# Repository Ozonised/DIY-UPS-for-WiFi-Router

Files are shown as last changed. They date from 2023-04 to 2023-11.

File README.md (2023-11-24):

# DIY-UPS-for-WiFi-Router
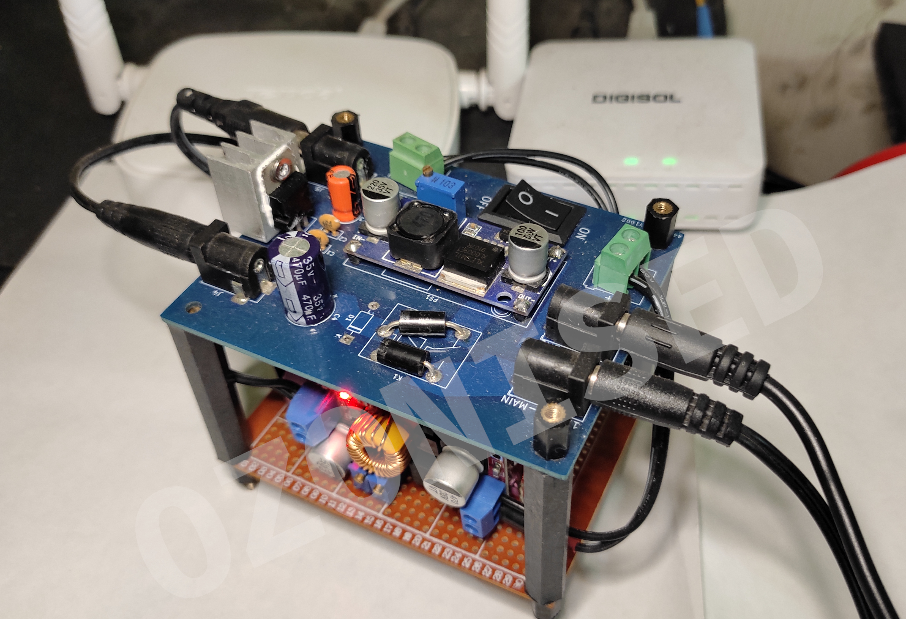
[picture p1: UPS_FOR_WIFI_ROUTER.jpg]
DIY_UPS_FOR_WIFI_ROUTER

A UPS for Wi-Fi routers and ONU with 4 hours of back-up.

# SPECIFICATIONS
Here is a breif table containing the main specs of the UPS:
| CATEGORY | VALUE |
| :---: | :---: |
| Back-UP time | Upto 4 hours|
| No. of Output ports | 2 |
| Output Voltage | 12V(1A) & 9V(800mA) |
| Input Voltage | 12V |
| Battery Type | 2s-2p li-ion |
| Battery Voltage | 7.4V(nominal) |
| Battery Capacity | 4000mAH |

# POWER
Unlike many commercial devices, this DIY UPS utilises 2 * 12 volt adapter. One for powering the Router and ONU, and the other for charging the batteries.
The adapter connected to the female barrel port labelled ```12V-IN-MAIN``` powers both the router and ONU, while the one connected to the female barrel port labelled ```12-IN-2ND``` is used for the charging the battery.
However, using two adapters is not a must, the entire thing can be powered by a single 12 volt adapter. To do so follow these steps:
- Short the pads ```TP1``` & ```TP2``` on the bottomside of the PCB.
- Now, plug the 12V adapter to the female barrel port labelled ```12V-IN-2ND```.

### Note:
 When using a single 12V adpater to power as well as charge the batteries, do not plug the 12V adapter into the female barrel port labelled ```12V-IN-MAIN```. Use the port labelled ```12V-IN-2ND```. Also use an adapter rated at-least 1.5 amps(2A is preferrable).

# BATTERY PACK
The battery is a 2s 2p lithium-ion pack with a nominal voltage of 7.4 volts and a capacity of, 4000mAh approximately.
The batteries are managed by this HW-882 3 A BMS for 2s lithium-ion battery pack.
Soldering the components on the PCB is a straight forward as everything is labelled. This is why I decided to skip the soldering part and focus on the wiring of the battery pack and XL4015 to the PCB.

## WIRING OF THE BATTERY PACK
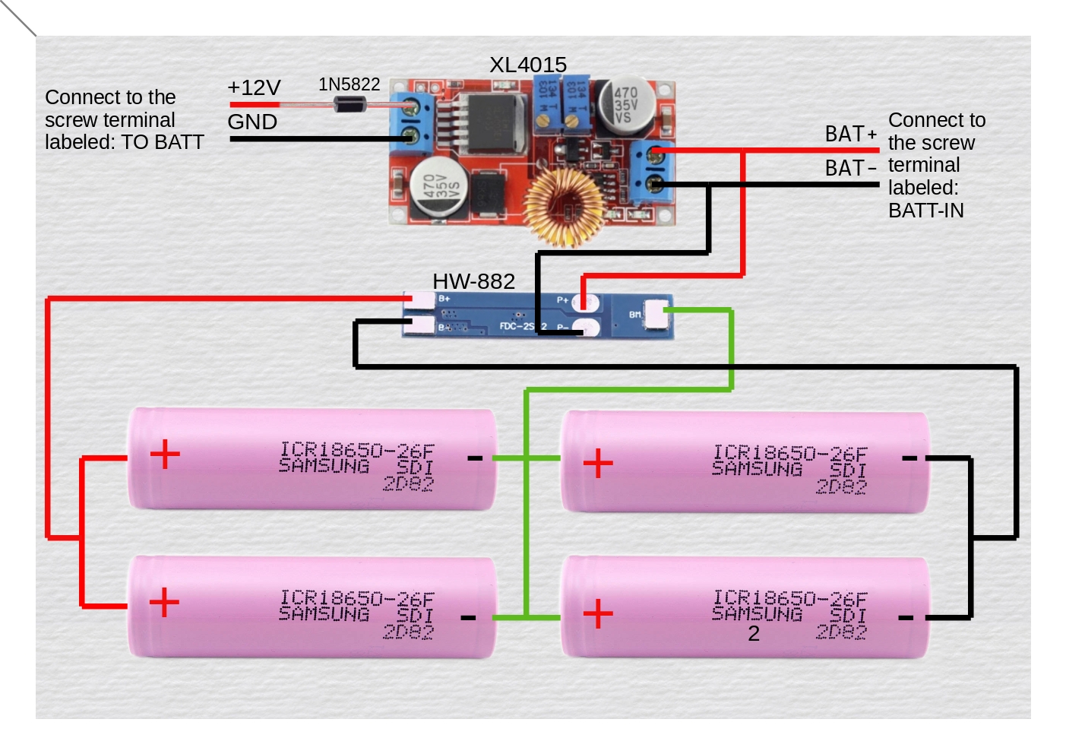
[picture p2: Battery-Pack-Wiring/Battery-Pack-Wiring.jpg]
Battery-Pack-Wiring

### Note:
Set the voltage and current on the XL4015 buck converter to 8.35 volts and 1.35 amps respectively before connecting it to the battery.

## WIRING BATTERY PACK TO THE PCB
Below are the steps to wire the battery pack and the XL4015 to the main PCB:
- The input from the battery connects to the srew terminal labelled ```BATT-IN```. 
- The input wires of the XL4015 plugs into the screw terminal labelled ```TO BATT```. 
### Note:
The positive side is marked by  ```+``` symbol beside screw terminal on the PCB.

# CHARGING SYSTEM
The batteries are charged by a XL4015 CC/CV 5A buck converter module, whose voltage and current must be set to 8.35 volts and 1.4 amps respectively.
The XL4015 module is powered by a 12V 2A adapter. If your 12V adapter is rated below 2A then lower the charging current on the buck converter to an appropriate level. Below are some reccommended charging current values in relation to the adapter's current rating:

| Adapter's Current Rating(A) | Charging Current(A) |
| :---: | :---: |
| 1 | 0.7 - 0.8 |
| 1.5 | 1 - 1.2 |
| 2 | 1.2 - 1.6 |

# PART LIST

| Part | Quantity |
| :---: | :---: |
| 0.1uF Cap | 2 |
| 220uF Cap | 1 |
| 470uF Cap | 1 |
| Female Barrel Jack | 4 |
| Male Barrel Jack | 4 |
| Screw Terminal_01x02 | 2 |
| XL6009 module | 1 |
| XL4015 CC/CV module | 1 |
| 7809 | 1 |
| Heat sink | 1 |
| SPST_Switch | 1 |
| HW-882 3 A BMS | 1 |
| 18650 2000mAH lion cell | 4 |
| 12V 2A adapter | 1 |
| 12V 1A adapter | 1 |

In additon to the items mentioned above, you will also need some other miscellaneous stuff like wires, etc.

# CREDITS:
I would like to take a moment to thank the YouTube channel [Open Green Energy](https://www.youtube.com/c/OpenGreenEnergy) for his video series on DIY UPS for WiFi Routers. They have been of huge help to me for the development of this project.

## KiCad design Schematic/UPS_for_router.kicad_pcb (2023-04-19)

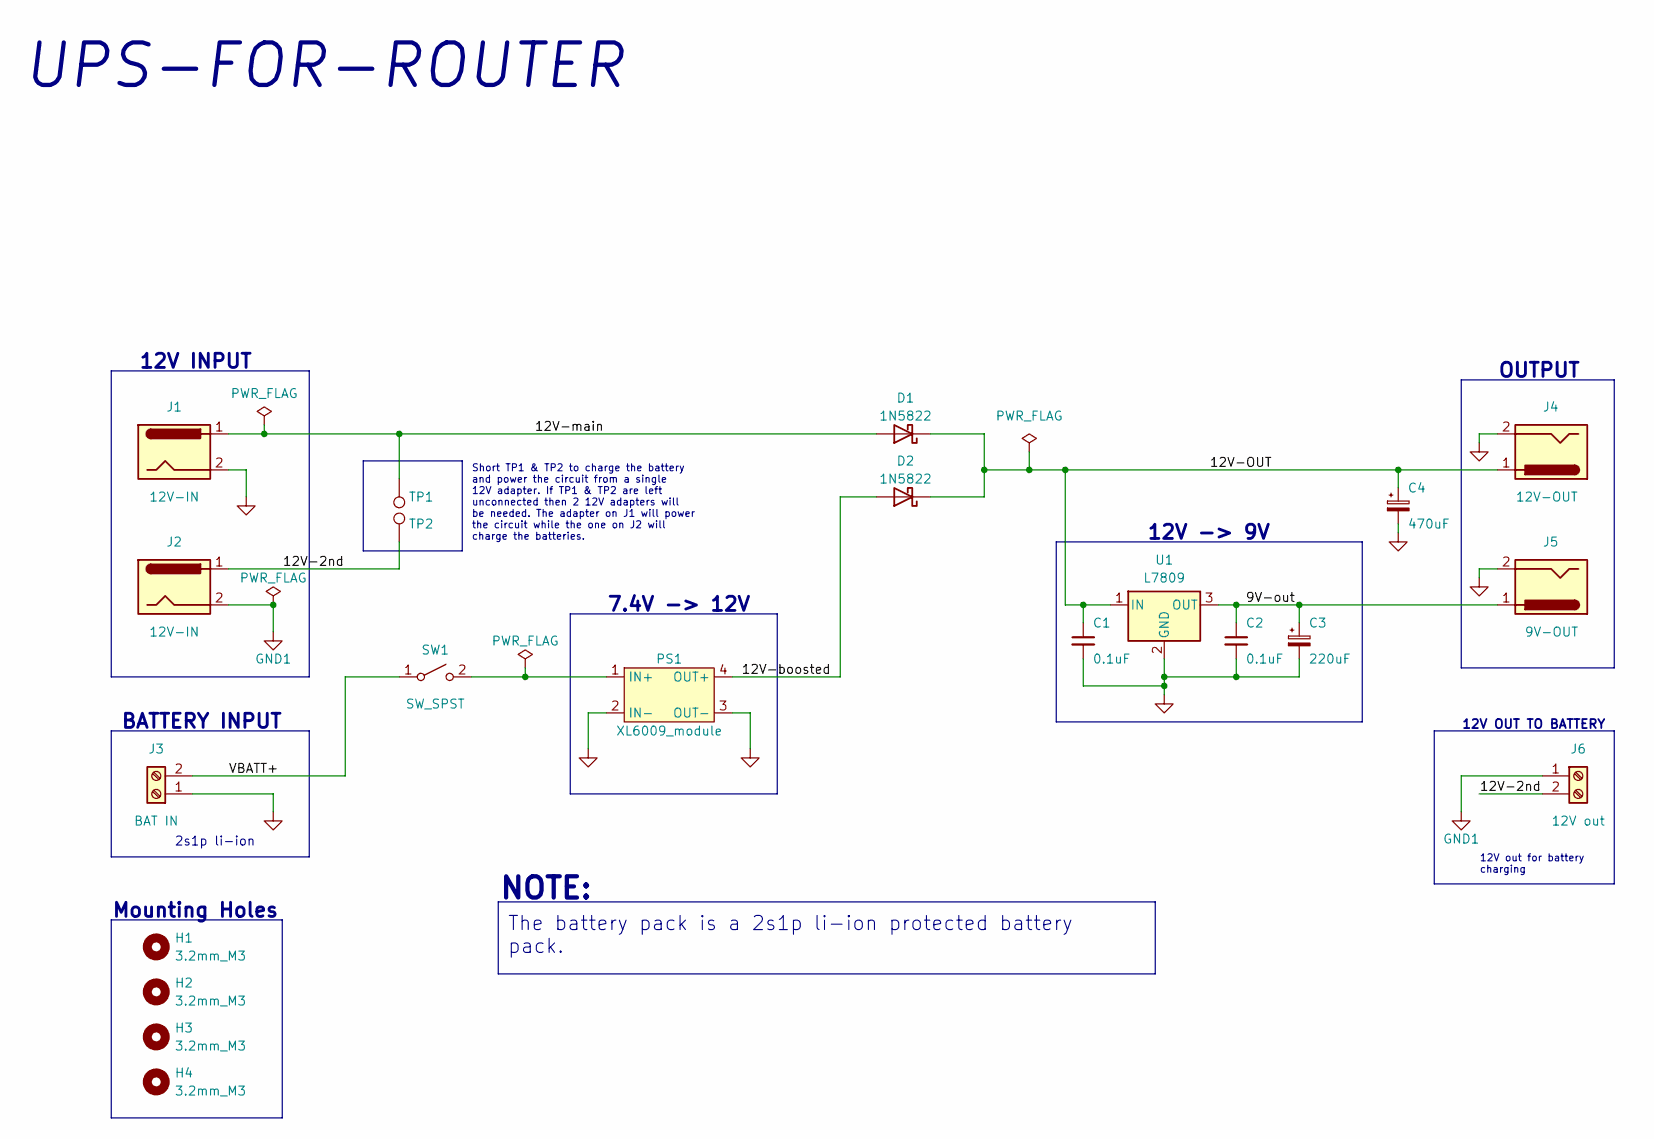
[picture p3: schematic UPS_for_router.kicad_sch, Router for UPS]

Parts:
C1, C2: 0.1uF; C_Disc_D5.0mm_W2.5mm_P2.50mm
C3: 220uF; CP_Radial_D6.3mm_P2.50mm
C4: 470uF; CP_Radial_D10.0mm_P5.00mm
D1, D2: 1N5822; D_DO-201AD_P15.24mm_Horizontal
H1, H2, H3, H4: 3.2mm_M3; MountingHole_3.2mm_M3
J1, J2: 12V-IN; BarrelJack_Horizontal
J3: BAT IN; TerminalBlock_Altech_AK300-2_P5.00mm
J4: 12V-OUT; BarrelJack_Horizontal
J5: 9V-OUT; BarrelJack_Horizontal
J6: 12V out; TerminalBlock_Altech_AK300-2_P5.00mm
PS1: XL6009_module
SW1: SW_SPST; TestPoint_2Pads_Pitch5.08mm_Drill1.3mm
TP1, TP2: SolderBridge; TestPoint_Pad_2.0x2.0mm
U1: L7809; TO-220-3_Vertical

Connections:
/9V-out: C2.1, C3.1, J5.1, U1.3 (OUT)
/12V-2nd: J2.1, J6.2, TP2.1
/12V-OUT: C1.1, C4.1, D1.1 (K), D2.1 (K), J4.1, U1.1 (IN)
/12V-boosted: D2.2 (A), PS1.4 (OUT+)
/12V-main: D1.2 (A), J1.1, TP1.1
/VBATT+: J3.2, SW1.1 (A)
GND: C1.2, C2.2, C3.2, C4.2, J1.2, J3.1, J4.2, J5.2, PS1.2 (IN-), PS1.3 (OUT-), U1.2 (GND)
GND1: J2.2, J6.1
unnamed: PS1.1 (IN+), SW1.2 (B)

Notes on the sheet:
12V OUT TO BATTERY
12V -> 9V
12V out for battery charging
12V INPUT
NOTE:
OUTPUT
Short TP1 & TP2 to charge the battery and power the circuit from a single 12V adapter. If TP1 & TP2 are left unconnected then 2 12V adapters will be needed. The adapter on J1 will power the circuit while the one on J2 will charge the batteries.
Mounting Holes
2s1p li-ion
7.4V -> 12V
UPS-FOR-ROUTER
The battery pack is a 2s1p li-ion protected battery pack.
BATTERY INPUT

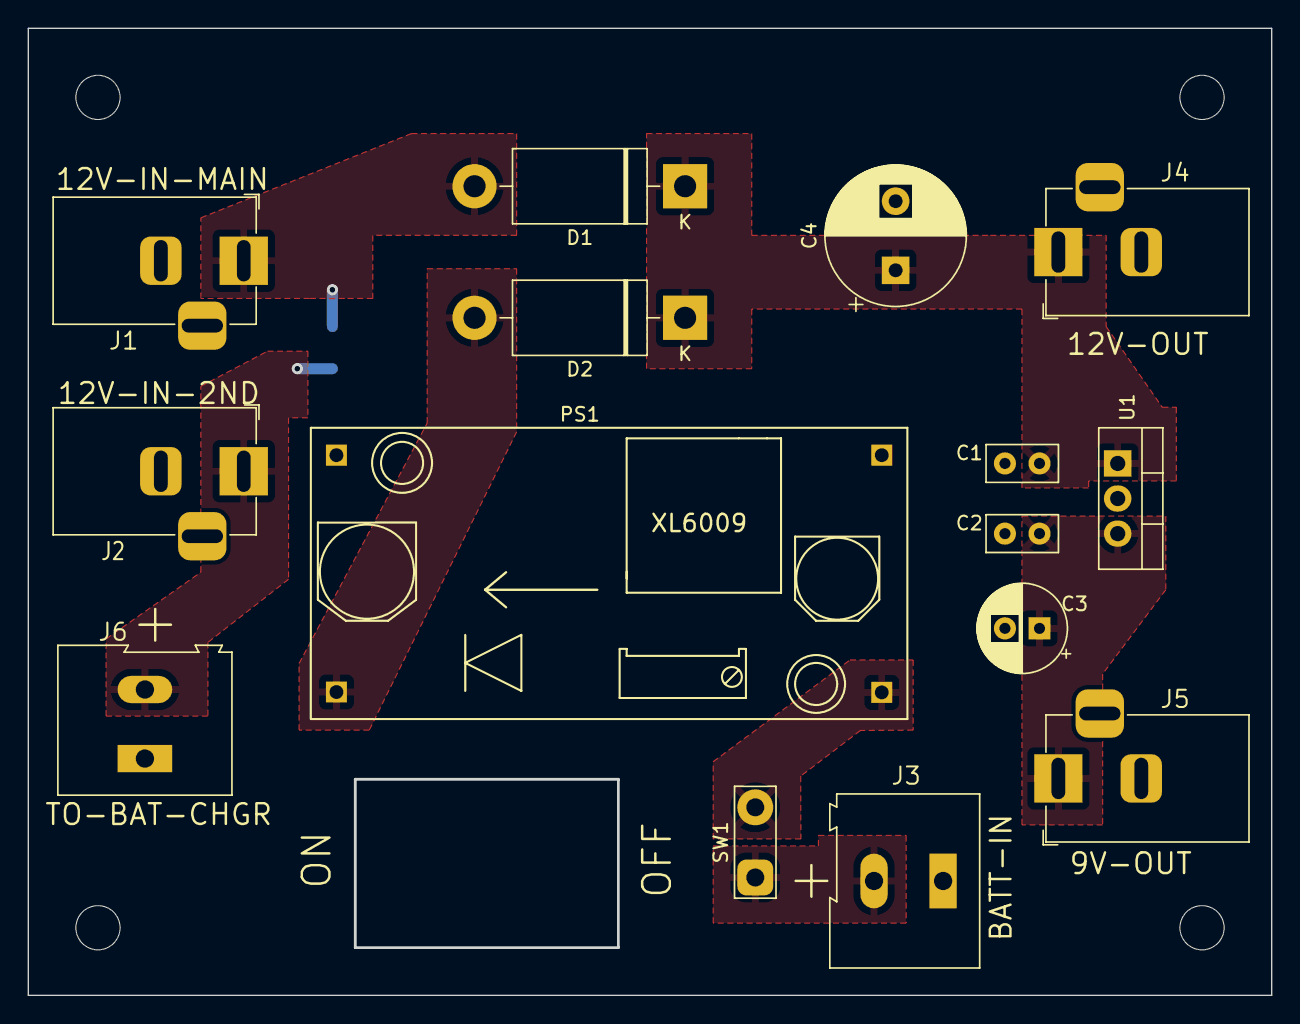
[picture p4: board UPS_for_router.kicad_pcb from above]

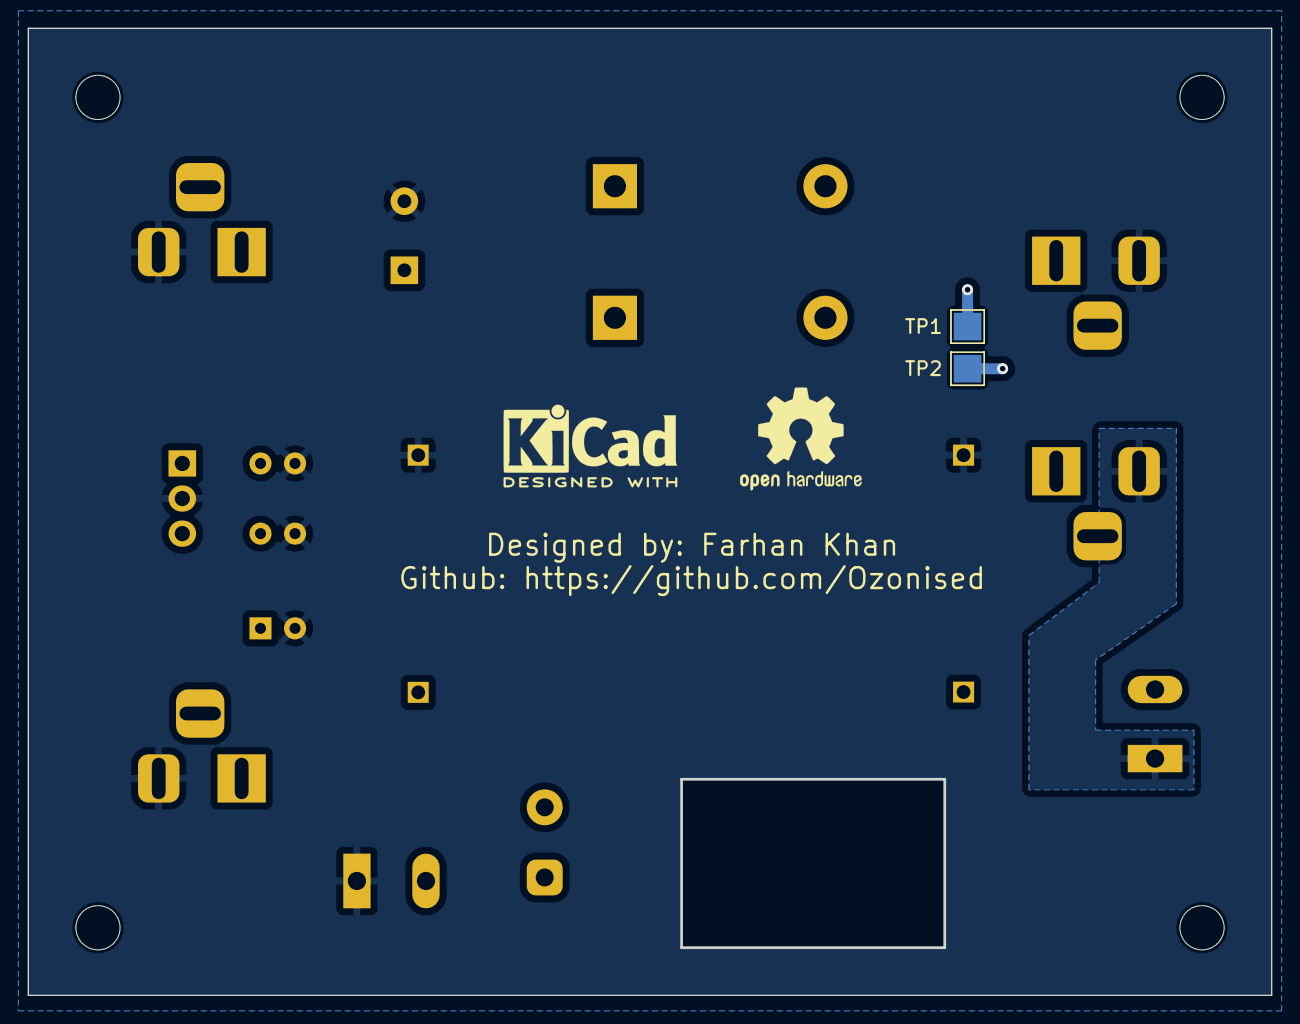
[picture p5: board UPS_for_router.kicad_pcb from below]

Board: 2 copper layers, 90.0 x 70.0 mm, 21 parts (2 on the bottom side), 9 nets.

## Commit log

2023-04-18 updated schematic and PCB
    removed relay and added diode as well as updated the PCB
    [UPS_for_router.kicad_pcb, UPS_for_router.kicad_sch]
2023-04-19 generated gerbers for rev2
    [UPS_for_router-B_Cu.gbl, UPS_for_router-B_Mask.gbs, UPS_for_router-B_Paste.gbp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]
2023-04-24 battery pack wiring
    added wiring diagram for battery pack
2023-04-24 updated battery pack wiring diagram
